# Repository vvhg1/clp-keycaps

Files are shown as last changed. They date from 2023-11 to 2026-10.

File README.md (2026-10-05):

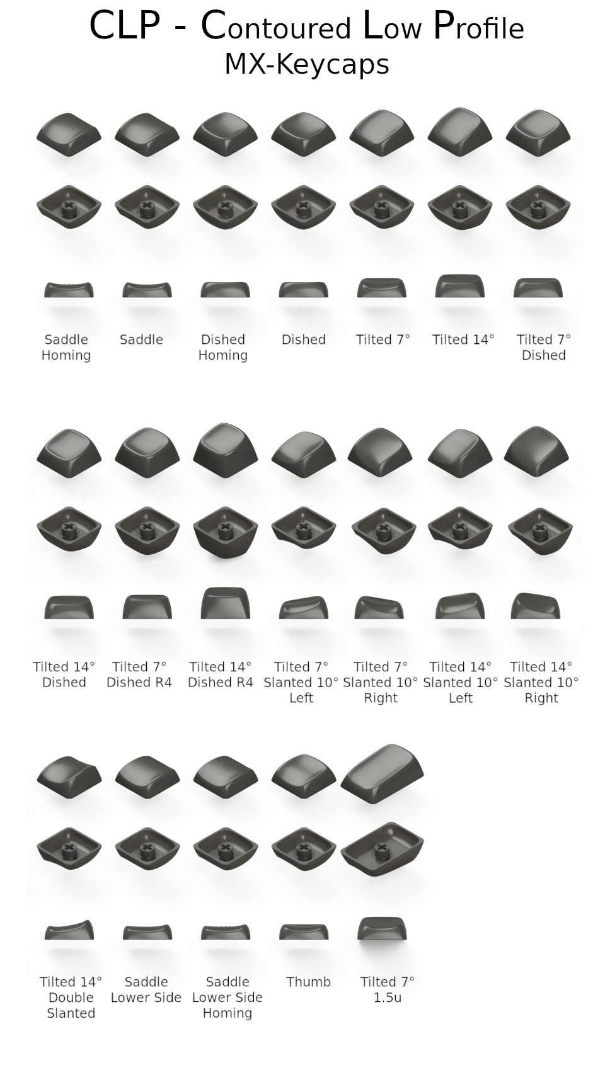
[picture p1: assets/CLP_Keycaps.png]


# CLP Contoured Low Profile MX Keycaps

The repository contains these folders:

| Folder | Purpose |
|---|---|
| **fusion360** | Source files for [Autodesk Fusion 360](https://www.autodesk.com/products/fusion-360/overview). |
| **fusion360/assemblies** | Combined source files of a maximum of 10 keycaps. These files are used to export the models to STL files. Combining models into one file is a good way to save money on printing as printing services often charge a minimum price per model. |
| **stl** | 3D models for any CAD or Slicer software. |
| **stl/assemblies** | Combined files that you can use in any 3D-printing service like [JLCPCB](https://3d.jlcpcb.com/3d-printing/stereolithography) or [PCBWay](https://www.pcbway.com/rapid-prototyping/3d-printing/). Combining models into one file is a good way to save money on printing as printing services often charge a minimum price per model. If you need other combinations, you can use the source files in the `fusion360/assemblies` folder to create your own STL files. |
| **assets** | Folder that contains images and actual photos of keycaps. |

There are currently 19 different keycap models available:

| Model | Description | STL | Fusion 360 |
|---|---|---|---|
| **Saddle Homing** | A saddle-shaped keycap, similar to the Chicago Steno keycaps, with three little bumps, commonly used for home row index fingers. | <a href="stl/CLP_Saddle_Homing v2.stl">Download</a> | <a href="fusion360/CLP_Saddle_Homing v2.stl">Download</a> |
| **Saddle** | A saddle-shaped keycap, similar to the Chicago Steno keycaps. | <a href="stl/CLP_Saddle v2.stl">Download</a> | <a href="fusion360/CLP_Saddle v2.stl">Download</a> |
| **Dished Homing** | A normal dished keycap with three little bumps, commonly used for home row index fingers. | <a href="stl/CLP_Dished_Homing v6.stl">Download</a> | <a href="fusion360/CLP_Dished_Homing v6.stl">Download</a> |
| **Dished** | A normal dished keycap. | <a href="stl/CLP_Dished v3.stl">Download</a> | <a href="fusion360/CLP_Dished v3.stl">Download</a> |
| **Tilted 7°** | Same as **Dished**, but top profile has a 7° tilt and the front is lowered. | <a href="stl/CLP_Tilt7 v8.stl">Download</a> | <a href="fusion360/CLP_Tilt7 v8.stl">Download</a> |
| **Tilted 14°** | Same as **Dished**, but top profile has a 14° tilt and the front is lowered. | <a href="stl/CLP_Tilt14 v10.stl">Download</a> | <a href="fusion360/CLP_Tilt14 v10.stl">Download</a> |
| **Tilted 7° Dished** | Same as **Tilted 7°**, but the top profile is dished. | <a href="stl/CLP_Dished_Tilt7 v3.stl">Download</a> | <a href="fusion360/CLP_Dished_Tilt7 v3.stl">Download</a> |
| **Tilted 14° Dished** | Same as **Tilted 14°**, but the top profile is dished. | <a href="stl/CLP_Dished_Tilt14 v3.stl">Download</a> | <a href="fusion360/CLP_Dished_Tilt14 v3.stl">Download</a> |
| **Tilted 7° Dished R4** | Same as **Tilted 7° Dished**, but higher profile for the top row. | <a href="stl/CLP_Dished_Tilt7_R4 v8.stl">Download</a> | <a href="fusion360/CLP_Dished_Tilt7_R4 v8.stl">Download</a> |
| **Tilted 14° Dished R4** | Same as **Tilted 14° Dished**, but higher profile for the top row. | <a href="stl/CLP_Dished_Tilt14_R4 v8.stl">Download</a> | <a href="fusion360/CLP_Dished_Tilt14_R4 v8.stl">Download</a> |
| **Tilted 7° Slanted 10°** | Same as **Tilted 7°**, but the top profile is slanted 10° to the left/right (two variants). | <a href="stl/CLP_Tilt7_Slant10 v17.stl">Download</a> | <a href="fusion360/CLP_Tilt7_Slant10 v17.stl">Download</a> |
| **Tilted 14° Slanted 10°** | Same as **Tilted 14°**, but the top profile is slanted 10° to the left/right (two variants). | <a href="stl/CLP_Tilt14_Slant10 v15.stl">Download</a> | <a href="fusion360/CLP_Tilt14_Slant10 v15.stl">Download</a> |
| **Tilted 14° Double Slanted** | Same as **Tilted 14°**, but the top profile is slanted to both sides, intended to go between two tilted keycaps. | <a href="stl/CLP_Tilt14_Doubleslant v6.stl">Download</a> | <a href="fusion360/CLP_Tilt14_Doubleslant v6.stl">Download</a> |
| **Saddle Lower Side** | Same as **Saddle**, but one side is lowered to have a better transition to the **Double Slanted** keycap. | <a href="stl/CLP_Saddle_LowSide v5.stl">Download</a> | <a href="fusion360/CLP_Saddle_LowSide v5.stl">Download</a> |
| **Saddle Lower Side Homing**  | Same as **Saddle Homing**, but one side is lowered to have a better transition to the **Double Slanted** keycap. | <a href="stl/CLP_Saddle_LowSide_Homing v1.stl">Download</a> | <a href="fusion360/CLP_Saddle_LowSide_Homing v1.stl">Download</a> |
| **Thumb** | Same as **Dished**, but with a lowered front side. | <a href="stl/CLP_Thumb v8.stl">Download</a> | <a href="fusion360/CLP_Thumb v8.stl">Download</a> |
| **Tilted 7° 1.5u** | Same as **Tilted 7°**, but 1.5u size. | <a href="stl/CLP_Tilt7_1_5u v13.stl">Download</a> | <a href="fusion360/CLP_Tilt7_1_5u v13.stl">Download</a> |

## How to print?

- For the best results, use a resin printer with a high resolution, or an online printing service like [JLCPCB](https://3d.jlcpcb.com/3d-printing/stereolithography) or [PCBWay](https://www.pcbway.com/rapid-prototyping/3d-printing/). JLCPCB SLS Nylon seems to work well too. MJF Nylon should probably work, but is untested and slightly more expensive.
- If you want to print the keycaps yourself, you can use the STL files in the `stl` folder. If you want to print multiple keycaps at once, you can use the STL files in the `stl/assemblies` folder. These files are already combined and ready to print.
- Some tips for FDM printing (thanks to [u/justapcgamer](https://www.reddit.com/user/justapcgamer/)):
  - use a 0.2mm nozzle, both surface feel and the dimensional accuracy of the keycap stem is so much better
  - if you cannot, use the finest layer height you are comfortable with, but 0.4mm nozzle prints generally require a good bit of post processing like trimming the insides of the stem
  - use as low of a layer height as you can
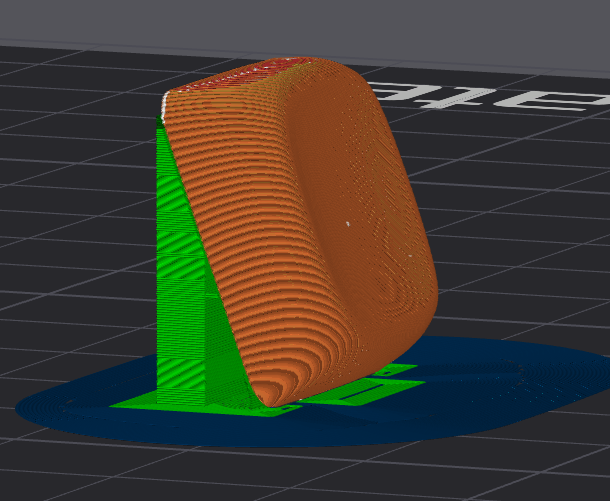
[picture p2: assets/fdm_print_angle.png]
  - print on bottom edge of one of the sides at an angle between 60-80 degrees, depending on which slice has a surface quality you like. 80 will result in a better surface but overhangs are rough. This image is 70 degrees: 
  - do not use supports for the inside of the stem, mark it for no supports in the slicer
  - use supports for the top edge so the underside doesn't sag and interfere with the switch
  - print in batches, if printing single keycap, increase the cooling. Since its small, if you print multiple, there's adequate time for cooling which results in better surfaces
  - if your printers toolhead has better cooling on one side, make sure the keycaps surface (side that touches your finger) faces the better cooled side for a better finish.
  - matte filaments will feel a bit rough, silk pla will feel slippery, I find normal pla gives the best finish.

## Images

SLS Nylon keycaps:
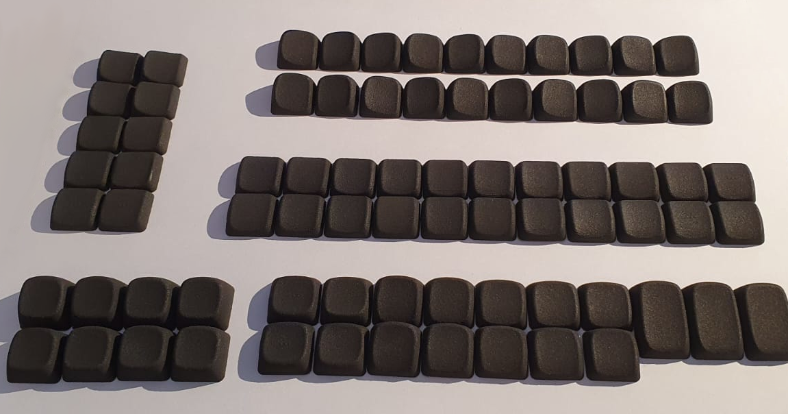
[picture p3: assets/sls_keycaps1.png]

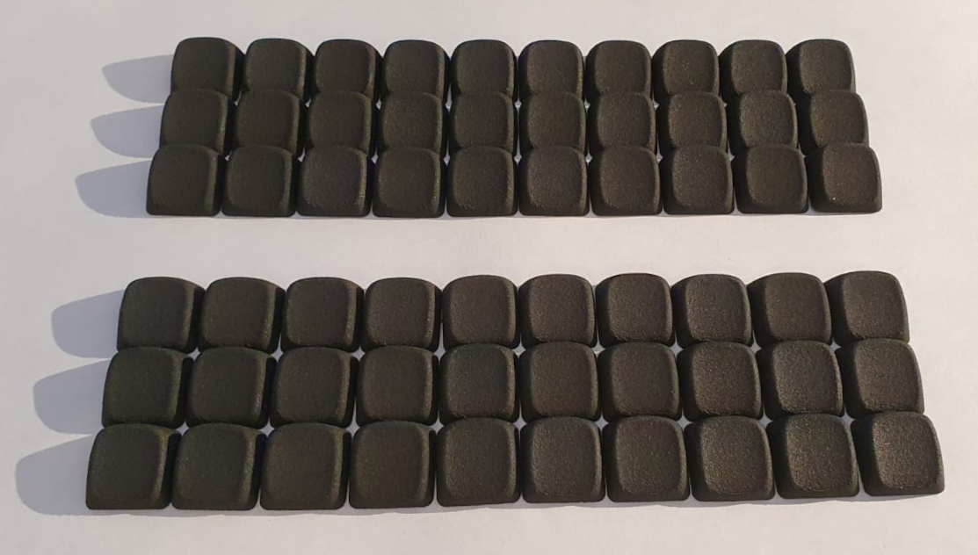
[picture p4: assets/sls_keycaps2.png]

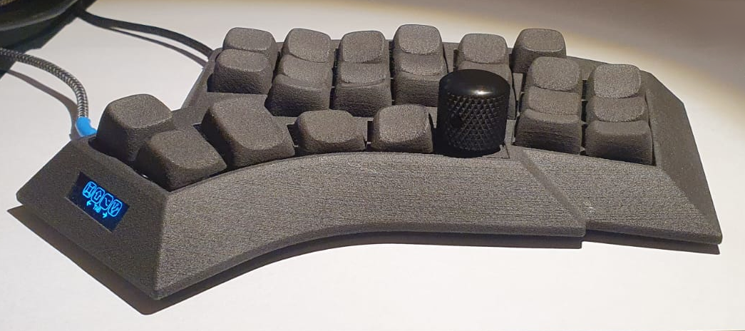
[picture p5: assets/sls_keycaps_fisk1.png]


so how low profile are these keycaps?
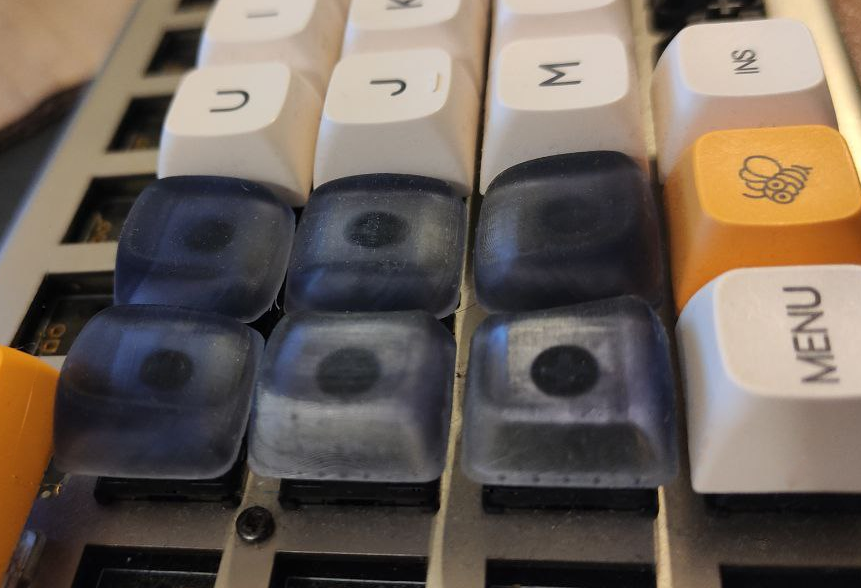
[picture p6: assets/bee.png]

source: [u/braindefender](https://www.reddit.com/user/braindefender/)

freshly hatched keycaps:
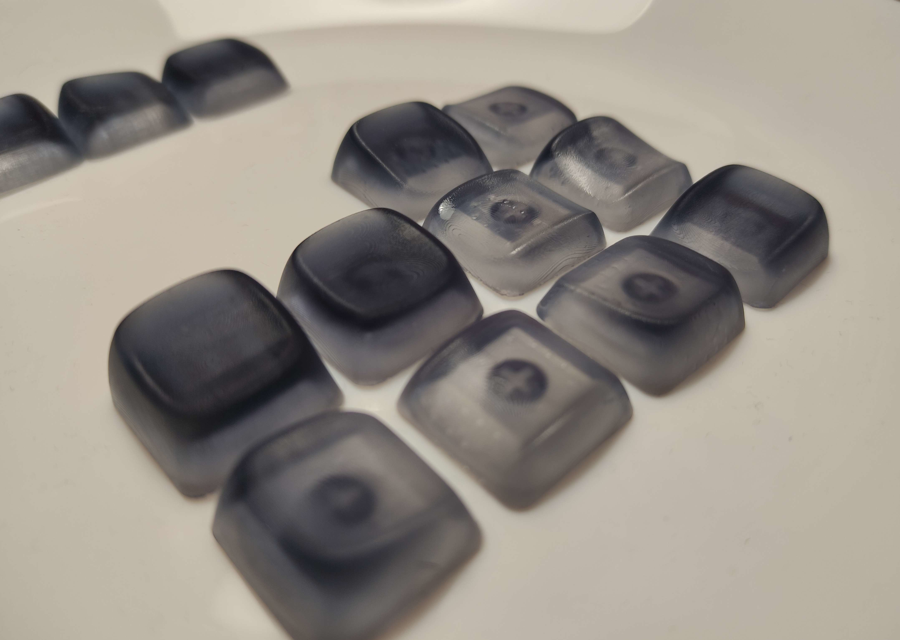
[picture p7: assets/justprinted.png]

source: [u/braindefender](https://www.reddit.com/user/braindefender/)

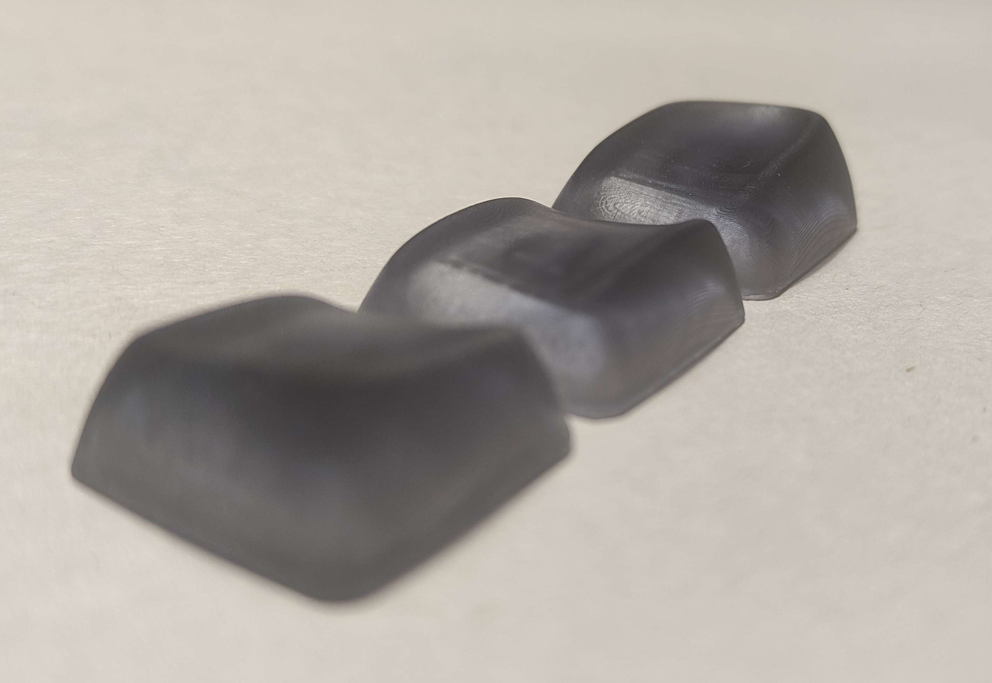
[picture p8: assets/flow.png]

source: [u/braindefender](https://www.reddit.com/user/braindefender/)


## Acknowledgements

As always this project wouldn't be possible without standing on the shoulders of giants. I took a lot of inspiration from braindefender's [KLP Lame keycaps](https://github.com/braindefender/KLP-Lame-Keycaps/). And sure enough, he was so kind to also provide excellent feedback (he alsocaught some nasty errors I overlooked!) and a bunch of tips and ideas. His experience with 3D printing keycaps was invaluable. He also did (well, still doing actually) a lot of test prints to check if the models are printable and work as expected. Thanks a lot, this would not have been possible without you, at least not at this level of quality and diversity!

Another source of inspiration was [Pseudoku's Distorted Ellipsoidal Saddle (DES) and Chicago Stenographer](https://github.com/toniz4/PseudoMakeMeKeyCapProfiles).

## License

All models are licensed under the GNU GPL v3 license. See the [LICENSE](./LICENSE) file for details.

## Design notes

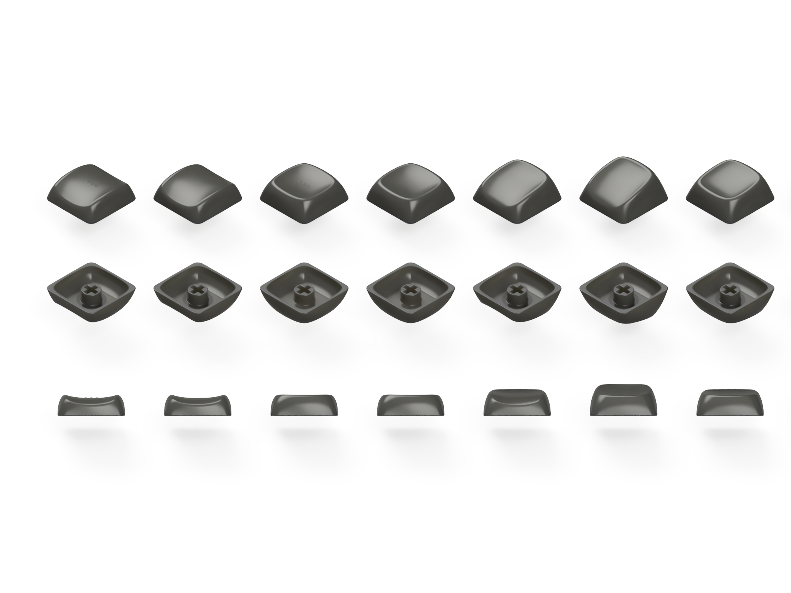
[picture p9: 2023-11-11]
assets/Render1.png

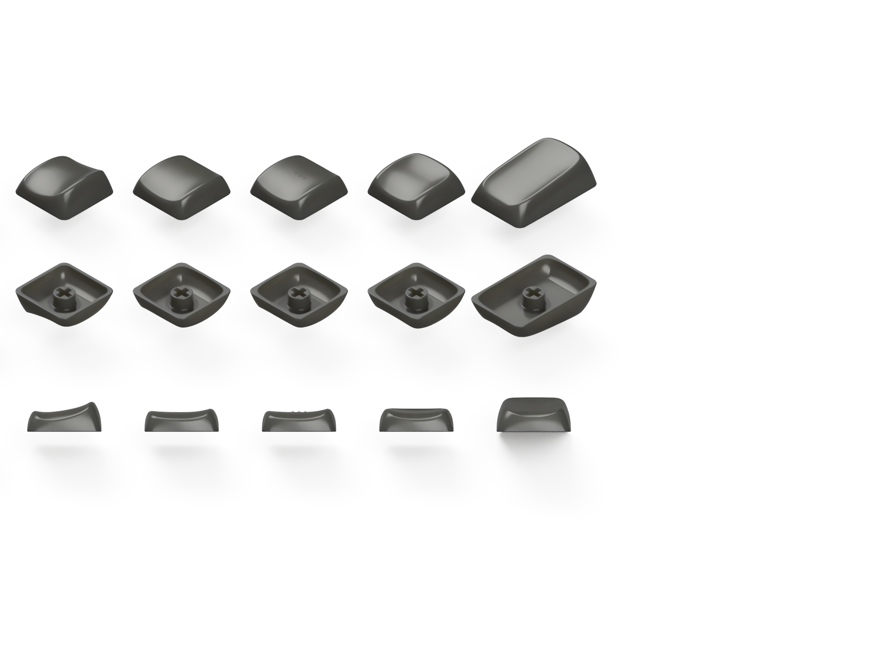
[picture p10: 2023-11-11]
assets/Render3.png

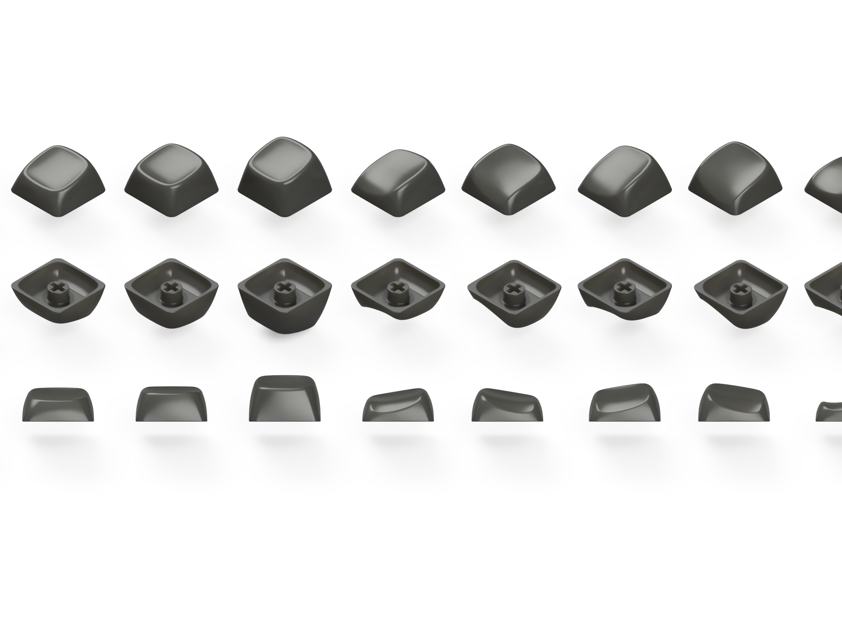
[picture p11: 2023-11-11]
assets/Render2.png

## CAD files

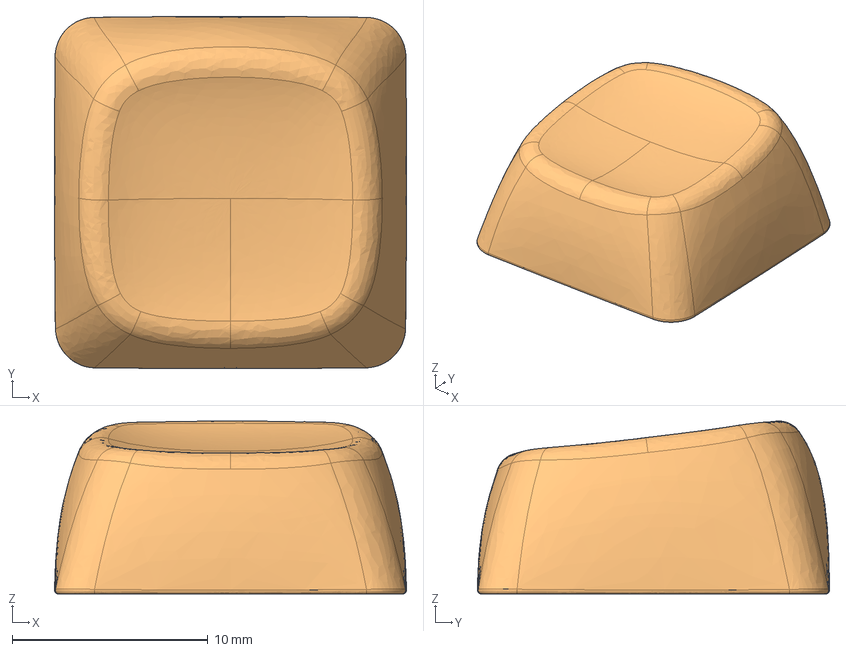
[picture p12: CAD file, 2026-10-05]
step/CLP_Dished_Tilt7_R4.step
18.0 x 18.0 x 8.84 mm

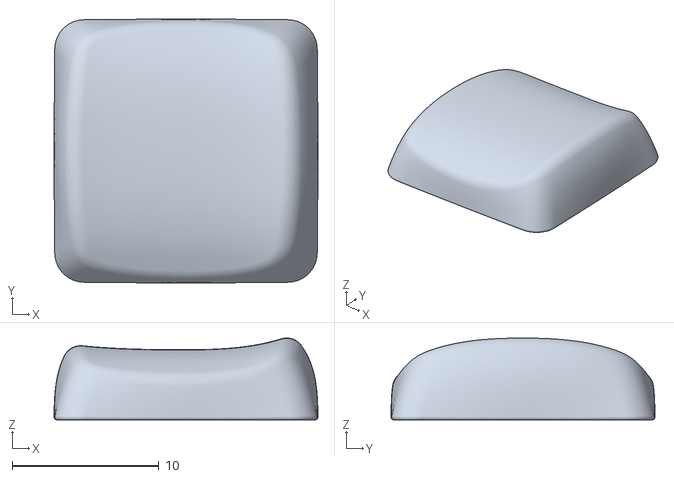
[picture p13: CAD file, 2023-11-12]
stl/CLP_Saddle_LowSide v5.stl
18.0 x 18.0 x 5.59

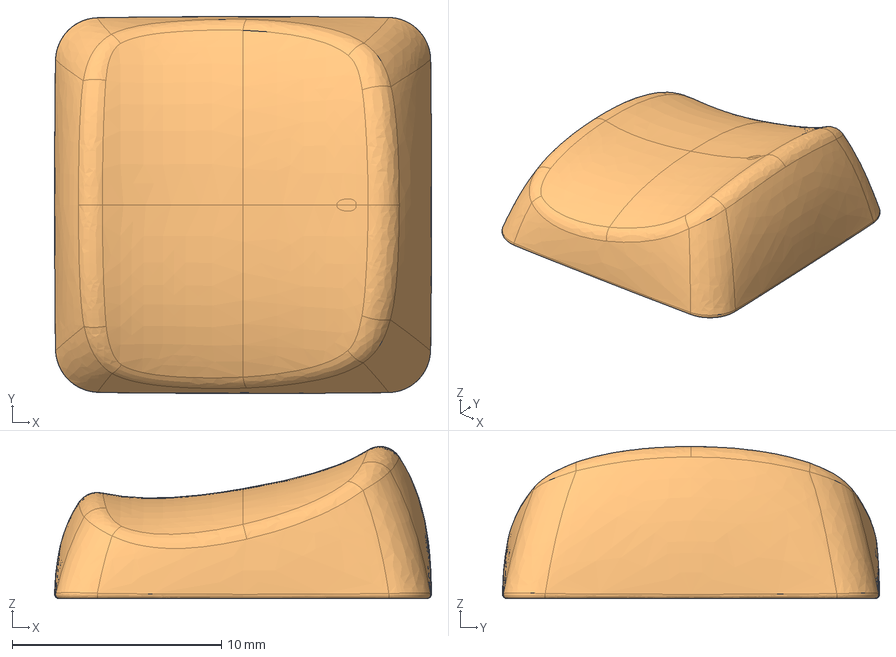
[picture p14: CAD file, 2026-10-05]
step/CLP_Tilt14_Doubleslant.step
18.0 x 18.0 x 7.26 mm

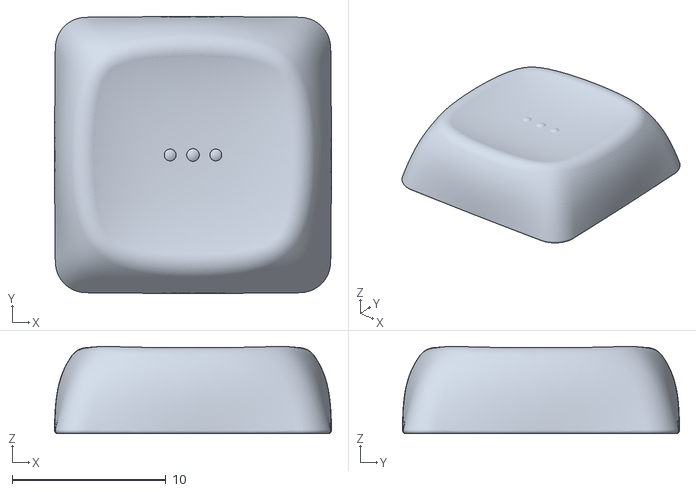
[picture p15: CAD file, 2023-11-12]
stl/CLP_Dished_Homing v6.stl
18.0 x 18.0 x 5.67

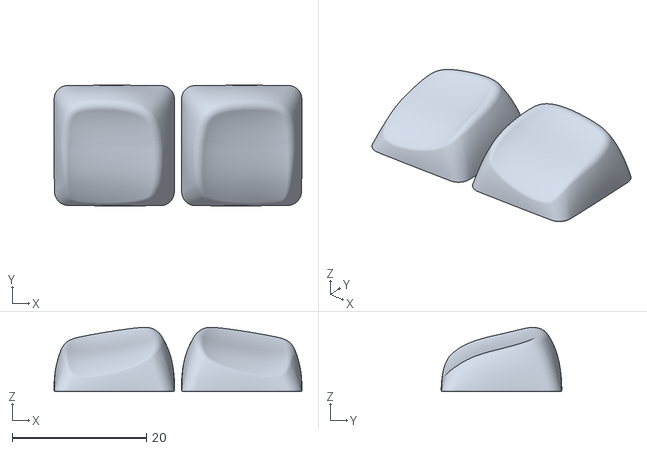
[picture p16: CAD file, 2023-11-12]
stl/CLP_Tilt14_Slant10 v15.stl
37.0 x 18.0 x 9.58

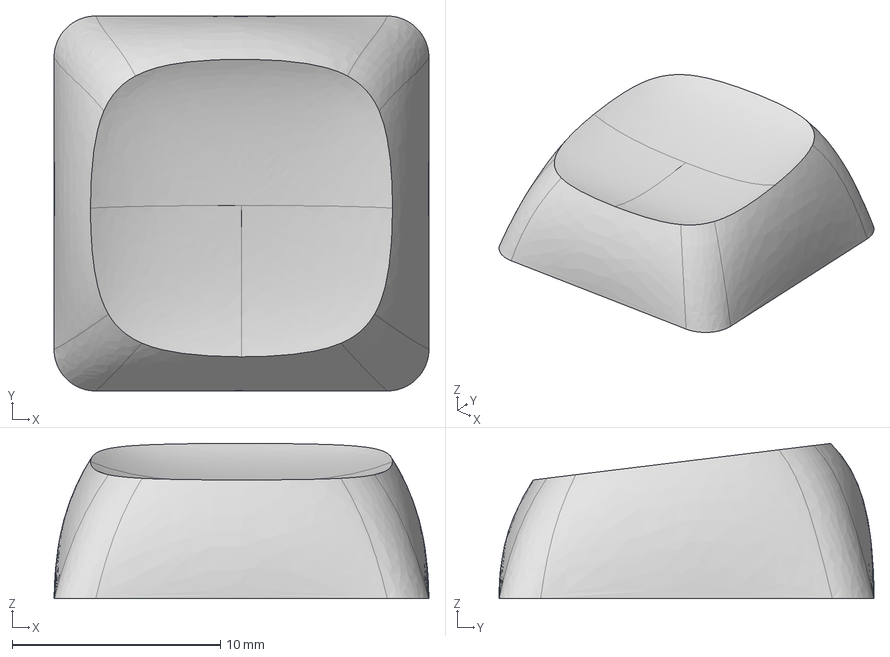
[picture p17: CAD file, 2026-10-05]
step/CLP_Base_Tilt7.step
18.0 x 18.0 x 7.45 mm

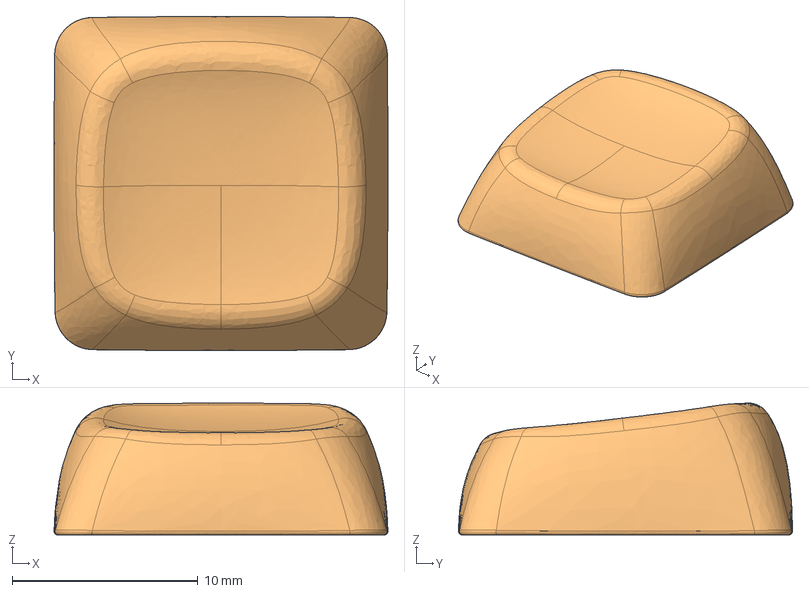
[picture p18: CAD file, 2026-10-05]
step/CLP_Dished_Tilt7.step
18.0 x 18.0 x 7.11 mm

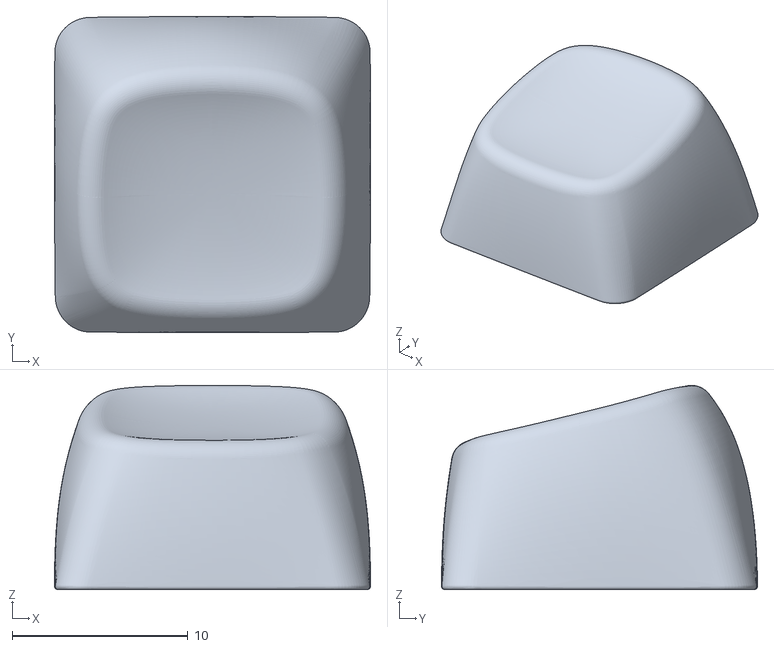
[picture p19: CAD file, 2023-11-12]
stl/CLP_Dished_Tilt14_R4 v8.stl
18.0 x 18.0 x 11.6

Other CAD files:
stl/assemblies/Assembly10Saddle v3.stl
stl/assemblies/Assembly10Tilt7 v4.stl
stl/assemblies/Assembly10of7Slanted v4.stl
stl/assemblies/Assembly10of14Slanted v3.stl
stl/assemblies/AssemblyThumbHoming v3.stl
stl/assemblies/AssemblyThumbOther v3.stl
stl/assemblies/Assembly4PairDoubleslantSaddleLowSideAndHoming v5.stl
stl/assemblies/Assembly10Tilt14 v5.stl
step/CLP_Thumb.step
stl/CLP_Saddle v2.stl
fusion360/CLP_Dished v3.f3z
fusion360/CLP_Dished_Homing v6.f3z
fusion360/CLP_Dished_Tilt14 v3.f3z
fusion360/CLP_Dished_Tilt14_R4 v8.f3z
fusion360/CLP_Dished_Tilt7 v3.f3z
fusion360/CLP_Dished_Tilt7_R4 v8.f3z
fusion360/CLP_Saddle v2.f3z
fusion360/CLP_Saddle_Homing v2.f3z
fusion360/CLP_Saddle_LowSide v5.f3z
fusion360/CLP_Saddle_LowSide_Homing v1.f3z
fusion360/CLP_Thumb v8.f3z
fusion360/CLP_Tilt14 v10.f3z
fusion360/CLP_Tilt14_Doubleslant v6.f3z
fusion360/CLP_Tilt14_Slant10 v15.f3z
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

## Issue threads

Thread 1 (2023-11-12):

Can't open file

firebone3, 2023-11-12:
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

can't open stl file in fusion 360
and f3z also opens only MX Plug Mushroom v4 file

vvhg1, 2023-11-12:
Which stl did you try to open?
Regarding the f3z files, regardless of which you try, it only opens the MX Plug Mushroom?

vvhg1, 2023-11-12:
@firebone3 I disabled lfs, that should hopefully resolve the issue, can you confirm please?

firebone3, 2023-11-13:
now files open normally.
Thank you

Closed 2023-11-13.

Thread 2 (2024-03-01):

Missing home keys

shawe, 2024-03-01:
I don't see any home keys, and without this keys is very hard put the fingers in the good place without look at the keyboard every time you want to use it.

On the other hand, congratulations for your work. I find it a very interesting set of keycaps.

shawe, 2024-03-01:
Sorry, I see now Saddle Homing key.

Closed 2024-03-01.

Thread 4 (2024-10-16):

Where to put which keys

eugenenelou, 2024-10-16:
Hey, thanks for this project it looks really cool.

I'm having troubles understanding which key goes where in the layout (for example the double slanted one), do you have an example layout?

I'm planning a 4x6 and am not sure what keys I should use in column 1 and 6.

vvhg1, 2024-10-17:
The double slanted can go onto the middle row, outer column where one finger has 6 keys to handle. Pairs with the saddle lower side on the middle row and slanted on rows 1 and 3 to form a dish over 6 keys. In general the idea is to have as smooth a transition between keys where you need it and as much tactile cue where the realm of one finger ends where you don't want transitions. If in doubt, experiment. Also have a look at my keyboard as an example, pics further down. Hope that helps!
-------- Original message --------From: Eugène Nélou ***@***.***> Date: 17/10/2024  00:12  (GMT+01:00) To: vvhg1/clp-keycaps ***@***.***> Cc: Subscribed ***@***.***> Subject: [vvhg1/clp-keycaps] Where to put which keys (Issue #4)
Hey, thanks for this project it looks really cool.
I'm having troubles understanding which key goes where in the layout (for example the double slanted one), do you have an example layout?
I'm planning a 4x6 and am not sure what keys I should use in column 1 and 6.

—Reply to this email directly, view it on GitHub, or unsubscribe.You are receiving this because you are subscribed to this thread.Message ID: ***@***.***>

eugenenelou, 2024-10-17:
Oh I understand, let me put a table so it's more visual if someone has the same question later.
|1|2|3|4|5|6|
|-|-|-|-|-|-|
|Slanted Right + Tilted|Slanted Left + Tilted|Tilted|Tilted|Slanted Right + Tilted|Slanted Left + Tilted|
| Double Slanted|Double Slanted|Saddled/Dished|Saddled/Dished|Double Slanted|Double Slanted|
|Slanted Left + Tilted|Slanted Right + Tilted|Tilted|Tilted|Slanted Left + Tilted|Slanted Right + Tilted|

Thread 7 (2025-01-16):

saddle keycaps trigger thin wall warning on jlc3dp

caut110, 2025-01-16:
`Assembly4PairDoubleslantSaddleLowSideAndHoming v5.stl` and `Assembly10Saddle v3.stl` trigger a thin wall warning on jlc3dp.

Content of email received from jlc3dp after placing my order:

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

I confirmed the order as it is in hope this can be ignored and results will be fine.

please close if irrelevant.

vvhg1, 2025-01-17:
The warning is expected, I had no issues so far. Please report back if you encounter any problems.

caut110, 2025-01-24:
Received the keycaps today, perfectly printed without any defects.

Closed 2025-01-24.

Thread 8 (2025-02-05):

Compatibility with Gateron KS-33 low profile

AnthonyVH, 2025-02-05:
As the title says, I'm wondering if these keycaps are compatible with Gateron KS-33 low profile switches. Do you have any idea?

kkruit, 2025-02-07:
They do fit on the KS-33 as KS-33 is MX compatible. I currently have a set on my nuphy moss switches and have had no issues.

Closed 2025-02-07.

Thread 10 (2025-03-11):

Print is missing stem

mononoken, 2025-03-11:
I loved the design of these keycaps, so I tried to get some printed at JLCPCB using PA12-HP Nylon. Many of them came out nicely, but the ones from [Assembly10Tilt7 v4.stl](https://github.com/vvhg1/clp-keycaps/blob/2c88449c58aaa70b0df80217440a9da647a46f91/stl/assemblies/Assembly10Tilt7%20v4.stl) and a few others did not print the stem. There is a circular recess where the stem should be. It doesn't look like the stem broke off as it seems smooth at the hole. Any idea what may have caused this?

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

Apologies as I have no experience with printing. Any advice is appreciated. Thank you!

mononoken, 2025-03-14:
I would advise caution printing from these files. I received this reply from JLC3DP:

> After double-checking with our engineer, all your files turn out some errors that cause the stems to not display properly.

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

This was received after printing a few of the assemblies and about 40% of them printing without stems.

vvhg1, 2025-03-21:
This is a mystery to me, I have had the stl files printed without issue by JLC3DP without any issues.
@mononoken thanks for the info, that should help narrow down the issue.
It will probably take a bit before I can fix this, as time is a scarce resource at the moment and I am not a 3D expert by any means, so I am slow and need to do a lot of reading up...

mononoken, 2025-03-21:
@vvhg1 no problem! It is def a mystery since scouring reddit and other sources, I haven't come across anyone else running into this issue. I'll try poking around too to see if I can fix it, but I am completely new to it so will take some time too if I can figure it out at all.

Thank you for designing these 🙂

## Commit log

2023-11-05 various fixes
    [Assembly10each7and14Slanted v3.f3z, Assembly10each7and14Slanted v3.stl, Assembly10each7and14Slanted v4.f3z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]
2023-11-06 fixed clearance with switch to 3.85 when pressed
    [Assembly10each7and14Slanted v4.f3z, Assembly10each7and14Slanted v4.stl, Assembly10each7and14Slanted v5.f3z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]
2023-11-09 updated stl
    [Assembly10Saddle v1.stl, Assembly10Saddle v2.stl, Assembly10Tilt14 v3.stl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]
2023-11-12 restore file contents previously tracked by lfs
    [Assembly10Saddle v3.f3z, Assembly10Tilt14 v5.f3z, Assembly10Tilt7 v4.f3z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]
2023-11-12 deleted some outdated files
    [CLP_Dished_Homing v5.f3z, CLP_Tilt14 v5.stl, CLP_Tilted7_R4 v12.f3z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]
2026-10-03 step: export for each keycap
    [CLP_Dished.step, CLP_Dished_Homing.step, CLP_Dished_Tilt14.step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]
2026-10-03 step: "base" files before cuts and fillets
    [CLP_Base.step, CLP_Base_Tilt14.step, CLP_Base_Tilt14_Doubleslant.step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]
